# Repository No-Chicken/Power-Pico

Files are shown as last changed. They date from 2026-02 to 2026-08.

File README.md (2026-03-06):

<p align="right">
  <b>中文</b> | <a href="./README_EN.md">English</a>
</p>

<div align="center">
  <h1 align="center">Power-Pico</h1>
  <p align="center">一款产品级的便携式 USB 电流表与低功耗测量分析仪</p>

  
  
  
  
  
  <br>
  
</div>

---

## 📖 项目简介

**Power-Pico** 不仅仅是一个 USB 电流表。它是专为嵌入式开发者设计的**高精度低功耗分析工具**。针对传统电流表在 $\mu A$ 级别测量时的物理局限性，Power-Pico 采用了创新的**多档位自动切换采样**设计，实现了从 $1\mu A$ 到 $5A$ 的全量程覆盖。

<p align="center">
	<a href="https://space.bilibili.com/34154740">bilibili主页 </a> |
	<a href="">演示视频 </a> |
    <a href="https://oshwhub.com/no_chicken/powerpico">硬件开源 </a>
</p>

<p align="center">
	
</p>

### ✨ 核心特性

- **uA 级高精度**：采用 INA190 零漂移放大器，配合三档电阻分段采样。
- **协议诱骗**：支持 PD2.0 PPS 协议诱骗，最高支持 20V/5A 诱骗输出。
- **高性能 UI**：基于 STM32F411 + LVGL v9.2，提供丝滑的实时波形显示。
- **优雅上位机**：配套 PySide6 开发的 Power-Pico Client，支持数据导出与实时功耗分析。
- **通用Type-C**：全部接口都是Typec-C，可以方便的外接Type-C转鳄鱼头等接头。
- **3D打印外壳**：提供完整的方便用户组装的 3D 打印外壳与亚克力面板设计方案。

---

## 🛠️ 硬件参数

<div align="center">

| 模块 | 选型 | 优势 |
| :--- | :--- | :--- |
| **主控** | STM32F411CEU6 | 100MHz 高主频，支持 DSP 指令加速波形处理 |
| **电流采样** | INA190 | 0.5nA 输入偏置电流，μA 级测量的核心保证 |
| **ADC** | 12-bit (STM32 Internal) | 配合 DMA 实现 10kHz 以上的高速稳定采样 |
| **屏幕** | 1.54" TFT (ST7789) | 240x240 分辨率，高对比度显示 |

</div>

---

## 🚀 快速复刻

### 1.硬件
自行焊接硬件，或购买淘宝已经焊接组装好的套件
立创硬件开源界面：https://oshwhub.com/no_chicken/powerpico

### 2. 固件自行编译烧录
项目基于 Keil MDK 开发：
1. 克隆仓库：`git clone https://github.com/kingham/Power-Pico.git`
2. SWD口烧录BootLoader
3. 自行编译PowerPico，编译好生成的`.bin`文件再使用PowerPico Client烧录即可

### 3. 结构组装

实物组装如下图所示:

<p align="center">
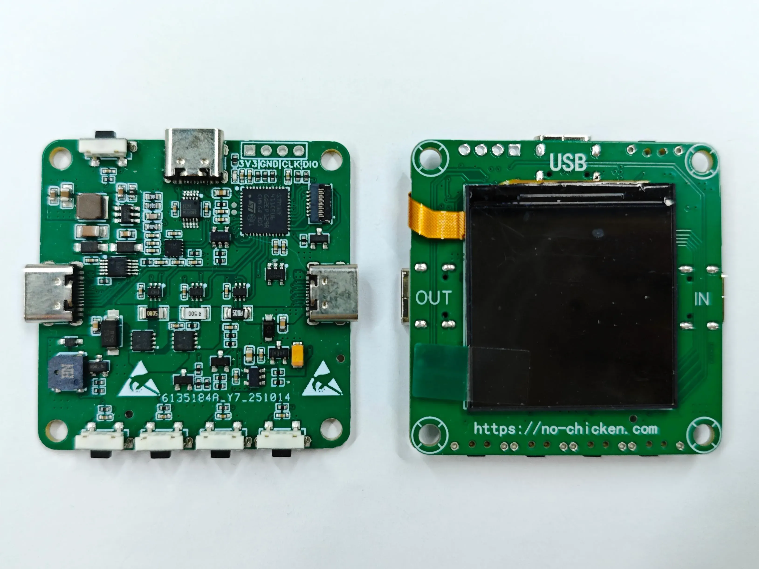
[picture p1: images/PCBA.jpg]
	
    &nbsp;
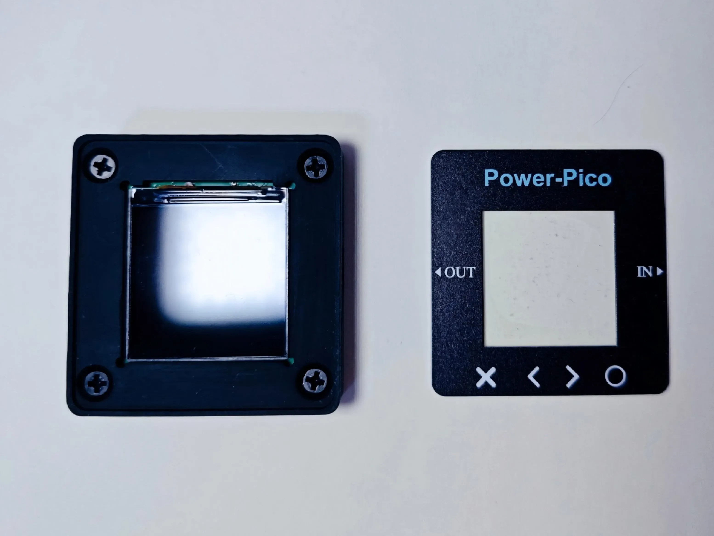
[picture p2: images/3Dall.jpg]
    
</p>

3D爆炸图如下图所示:

<p align="center">
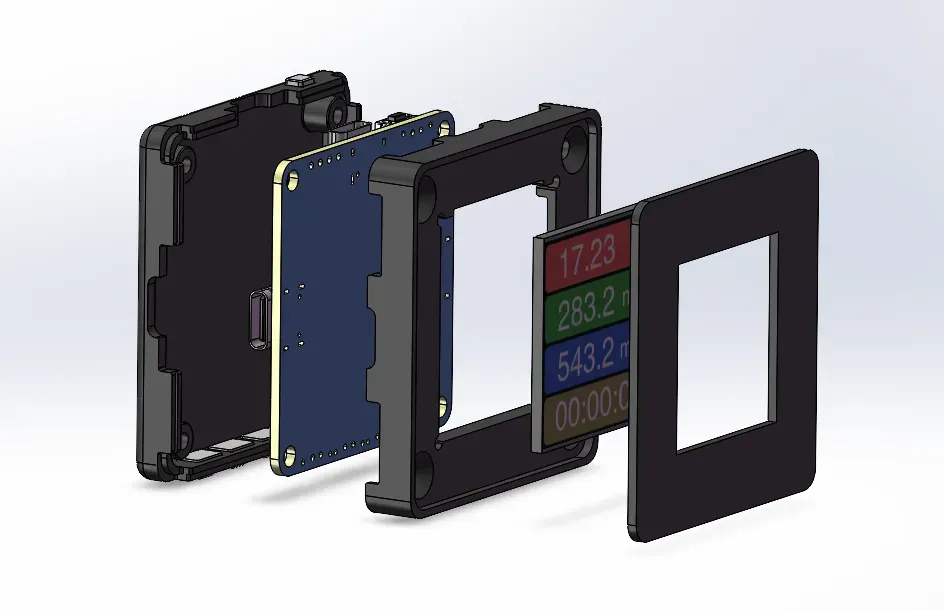
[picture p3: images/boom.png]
	
    &nbsp;
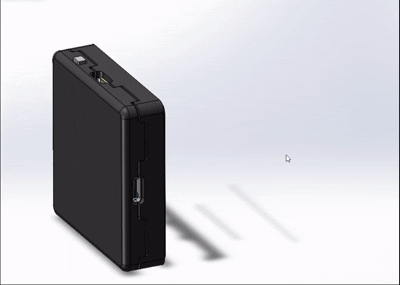
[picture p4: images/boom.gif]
    
</p>

### 4. 上位机运行
安装PowerPico Client使用即可，目前只支持windows操作系统。

## 🛠️ 使用说明

1. 硬件操作说明

    Power-Pico的按键操作说明，和各个界面展示，如下图所示。顶部按键为 **换页/Boot** 按键，长按住顶部按键再上电，会直接进入Boot模式强制升级模式。

    Power-Pico硬件目前只支持 **中文简体/English** 2种语言。

    <p align="center">
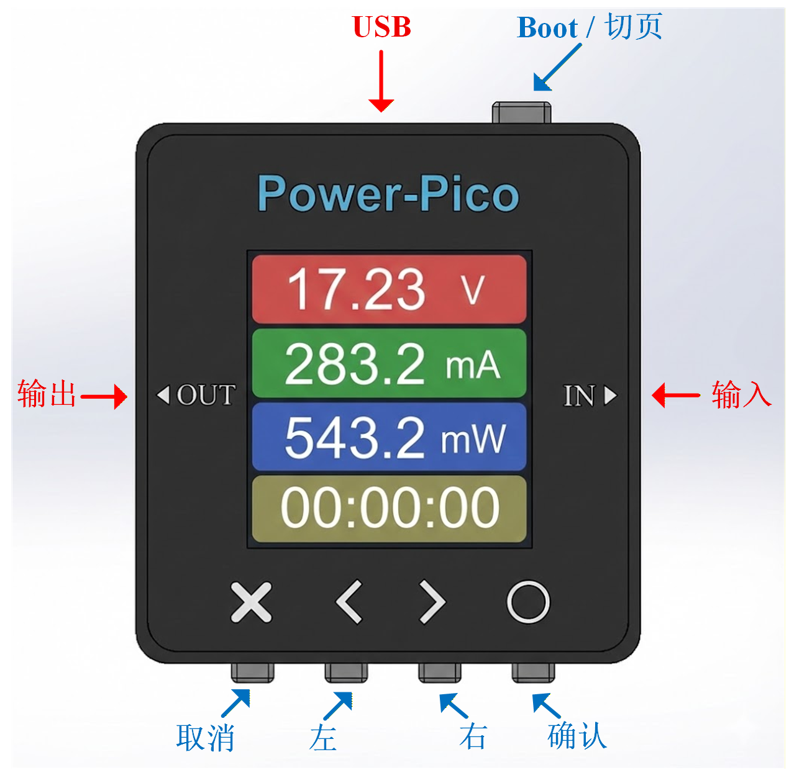
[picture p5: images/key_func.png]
        
        &nbsp;
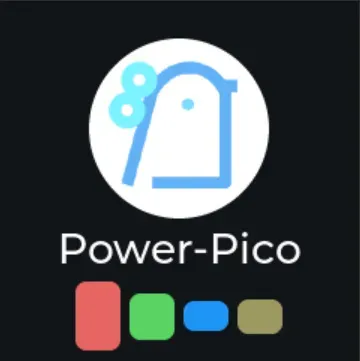
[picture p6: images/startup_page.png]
        
    </p>
    <p align="center">
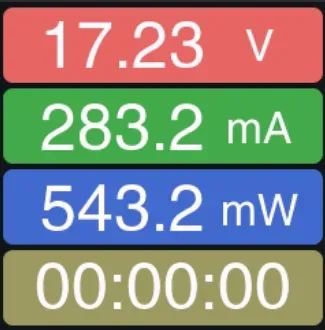
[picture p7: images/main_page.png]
        
        &nbsp;
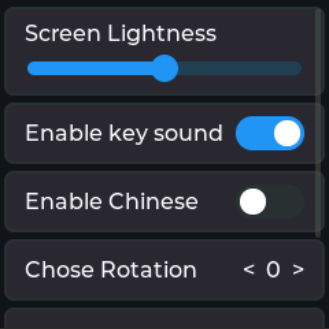
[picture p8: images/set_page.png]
        
    </p>
    <p align="center">
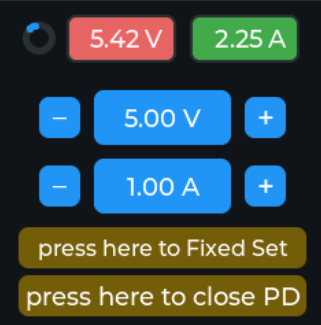
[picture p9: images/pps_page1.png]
        
        &nbsp;
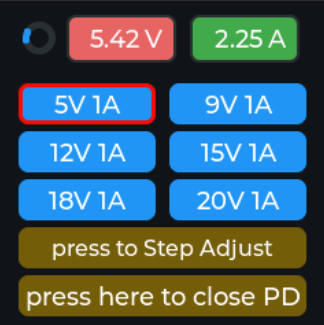
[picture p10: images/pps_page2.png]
        
    </p>

2. PPS诱骗操作说明

    首先进入setting界面，来到诱骗选项，点击确认，进入诱骗，然后即可进行电压调节。注意：目前只支持 PPS 诱骗！测试时需要看下充电头协议支持！

    <p align="center">
        
    </p>

3. 客户端操作说明

    PowerPico Client电脑客户端可以用于波形查看、记录、导出；能够进行对下位机硬件的固件升级。客户端目前支持 **中文简体/中文繁体/English/日本語** 4种语言。

    PowerPico Client客户端上位机的具体使用方法详见：[客户端操作说明](https://no-chicken.com/content/Power-Pico/UserManual/client_operation.html)

    <p align="center">
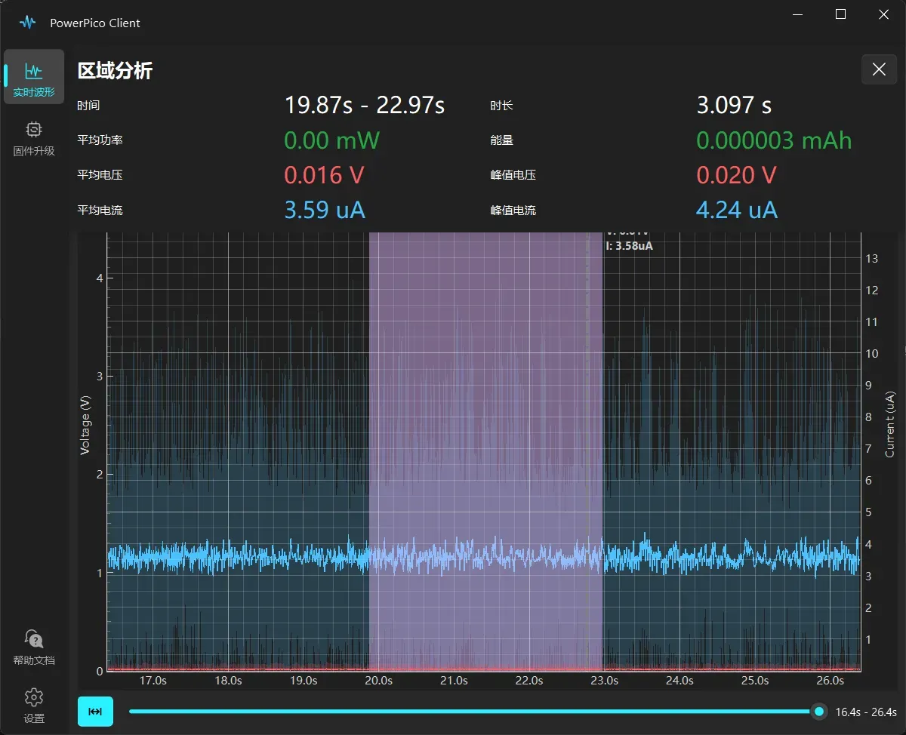
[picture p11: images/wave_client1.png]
        
        &nbsp;
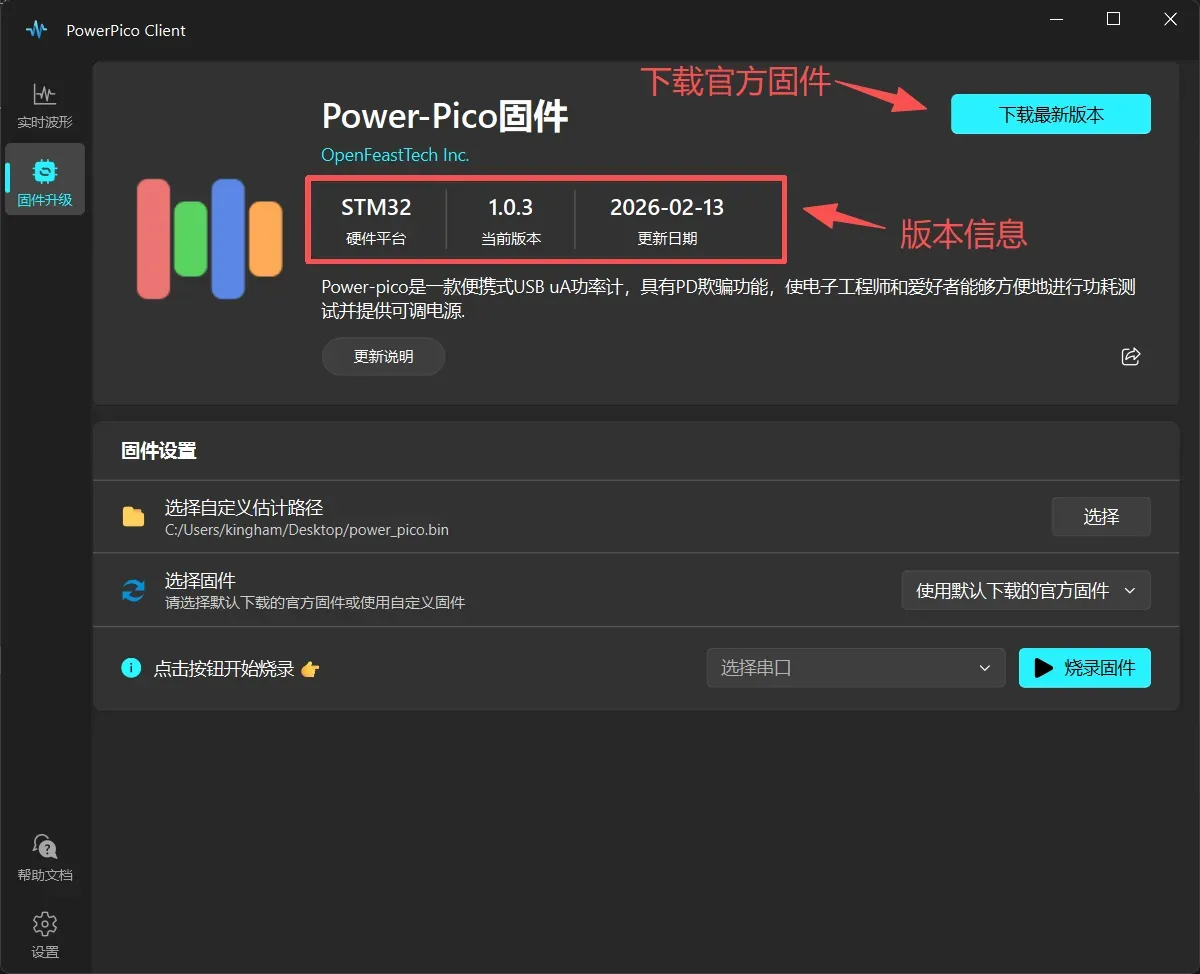
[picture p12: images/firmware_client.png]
        
    </p>
    <p align="center">
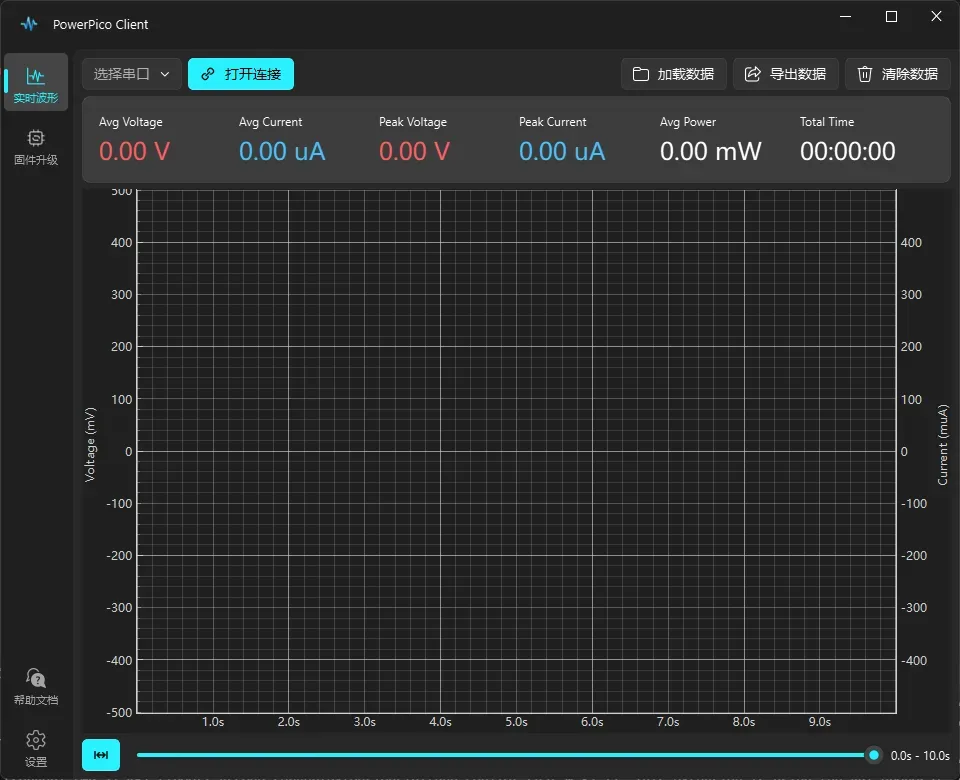
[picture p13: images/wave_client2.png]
        
        &nbsp;
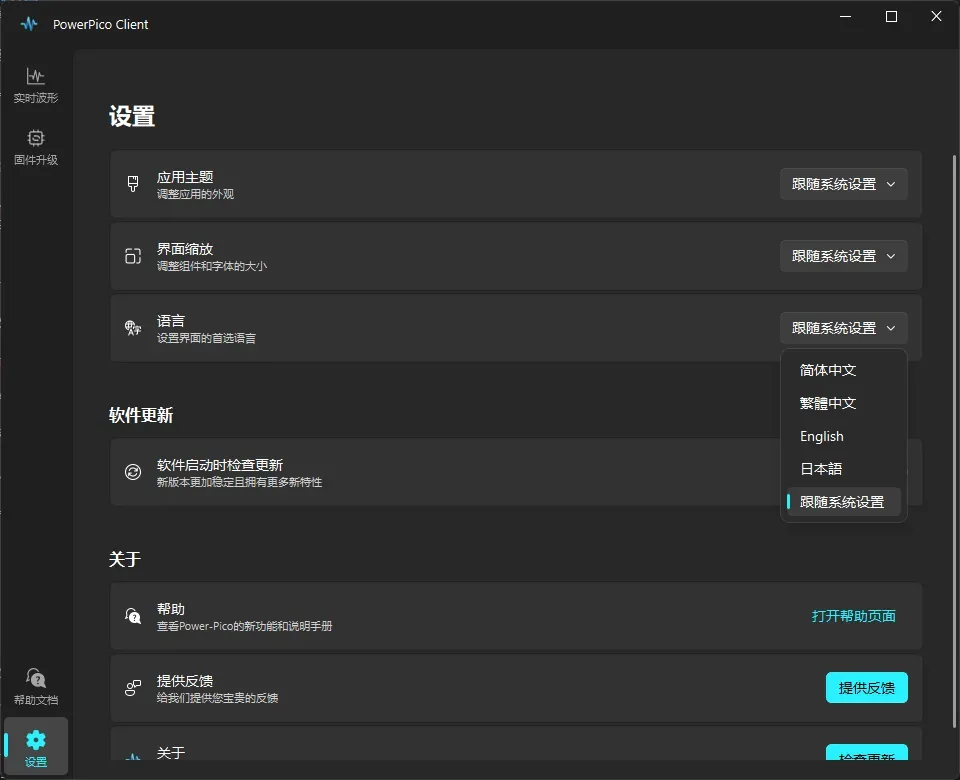
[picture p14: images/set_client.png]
        
    </p>

## 🔍️ 精度测量

<b>注意: Type-C接口线的电源和GND之间是有电阻的，一般是MΩ级别，会影响测量</b>

使用 SDM3055 六位半万用表进行对比，如下图所示：

<p align="center">
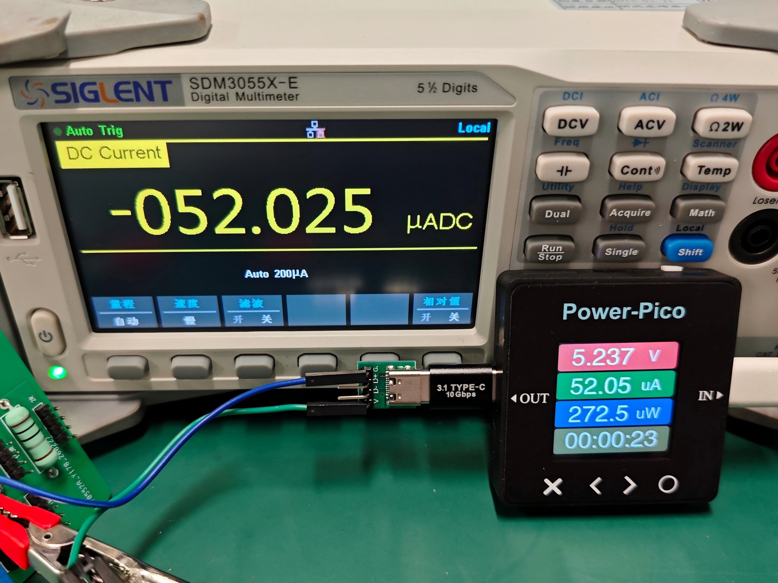
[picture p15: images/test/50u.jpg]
    
    &nbsp;
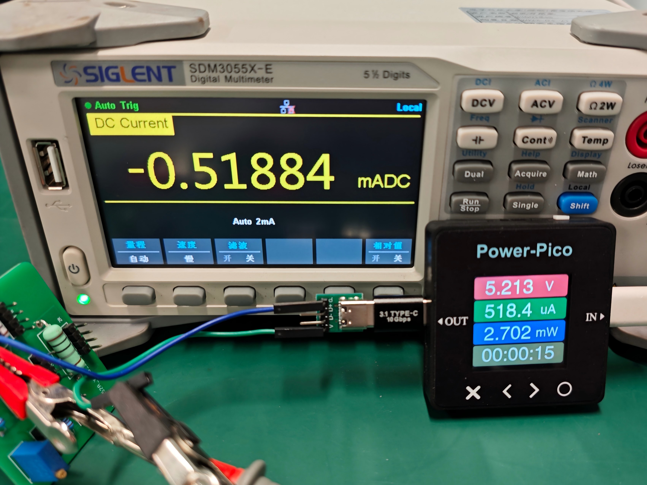
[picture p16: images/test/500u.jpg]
    
</p>
<p align="center">
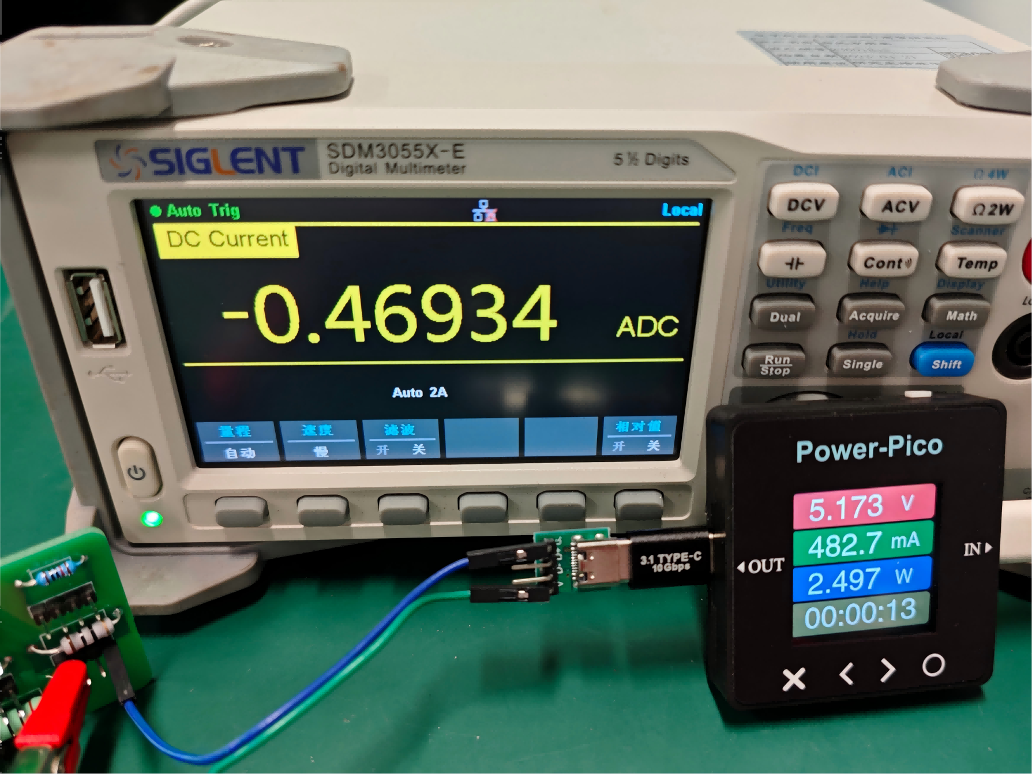
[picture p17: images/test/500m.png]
    
    &nbsp;
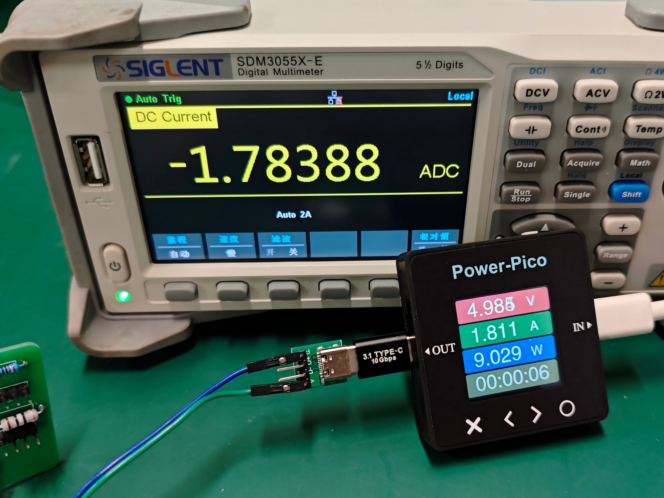
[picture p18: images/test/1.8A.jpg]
    
</p>

<div align="center">

| SDM3055示数 | Power-Pico示数 | 绝对误差 | 相对误差 |
| :--- | :--- | :--- | :--- |
| 52.03 uA | 52.05 uA | 0.02uA | 0.4% |
| 518.84 uA | 518.4 uA | 0.5 uA | 1.0% |
| 5.22 mA |	5.29 mA | 0.07 mA |	1.3% |
| 469.3 mA | 482.7 mA |	13.4 mA | 2.9% |
| 1.78 A | 1.81 A |	0.03 A | 1.7% |
| 5.19 V | 5.24 V | 0.05 V | 1.0% |
| 15.20 V | 15.56 V | 0.36 V | 2.4% |
| 19.98 V | 20.17 V | 0.19 V | 1.0% |

</div>

---

## 📂 项目结构
```text
Power-Pico/
├── Firmware/        # 固件，包括BootLoader.hex和App.bin
├── Hardware/        # 原理图
├── 3D models/       # STL文件，用于3D打印外壳
└── Software/        # PowerPico的MDK软件工程，包括BootLoader和App
```

---

## 💻代码框架

跟以前的项目一样，采用了 BootLoader + App 的结构，方便USB升级。程序分区如下图所示。

<ul>
<li>起始的sector0,1,2的48kB区域为BootLoader区域</li>
<li>第3个sector的16kB区域为升级信息区域，用于开机校检App完整性，具体的校检内容详见BootLoader代码</li>
<li>从0x08010000第4个扇区开始后的区域，都为App区域（之所以不做AB分区是片上Flash不够）</li>
</ul>

<p align="center">
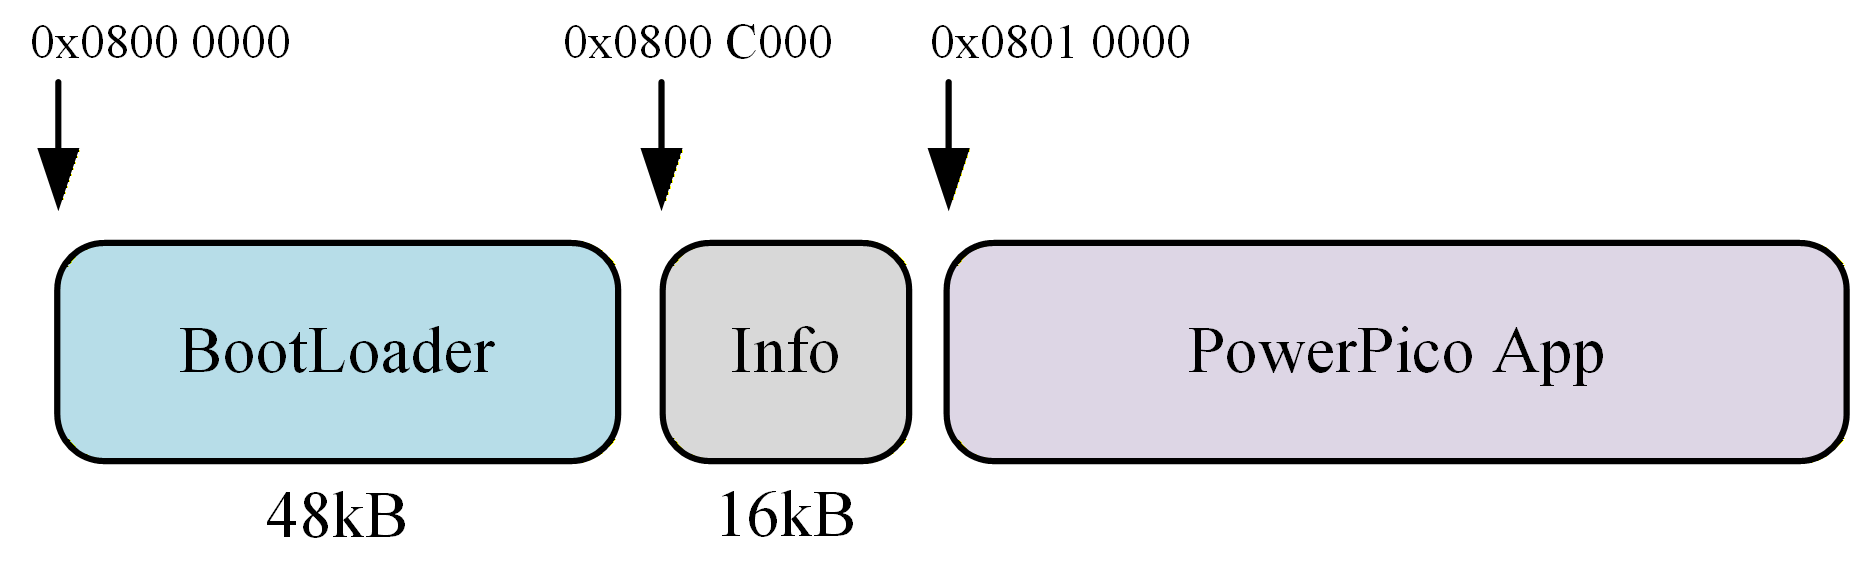
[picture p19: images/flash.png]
    
</p>

使用USB进行高速数据传输，数据包组成如下图所示。每个数据包100组数据，加上头共计711Bytes。

<p align="center">
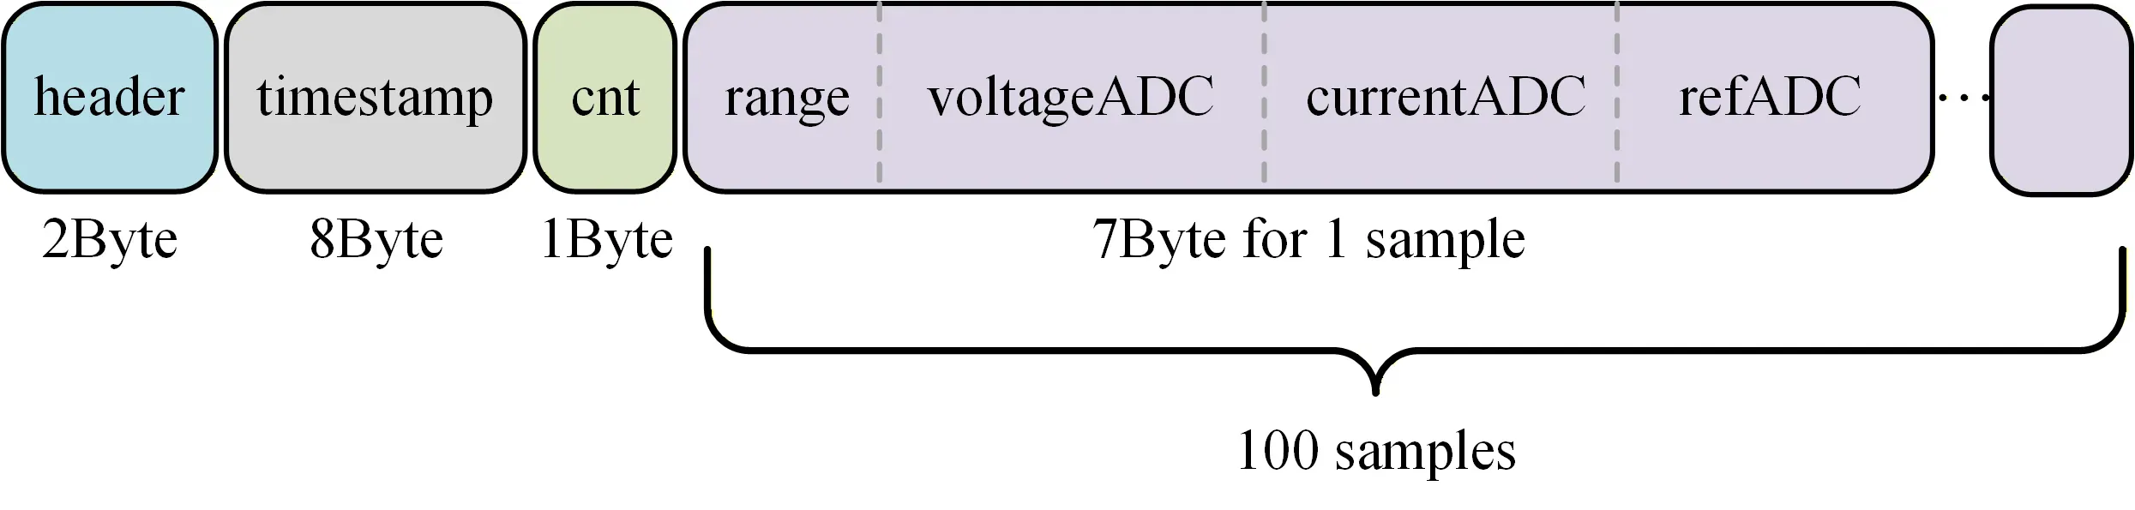
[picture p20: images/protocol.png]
    
</p>

---

## 📖 参考资料

<ul>
    <li style="margin-bottom:8px"><a href="https://github.com/ryan-ma/PD_Micro">[1] PD_Micro - ATMega32U4 Arduino板上的USB-C PD3.0 PPS</a></li>
    <li style="margin-bottom:8px"><a href="https://wiki.luatos.com/iotpower/cc/index.html">[2] 合宙 Power CC 外壳结构</a></li>
    <li style="margin-bottom:8px"><a href="https://doc.qt.io/qtforpython-6/PySide6/QtWidgets/index.html">[3] PySide6手册</a></li>
    <li style="margin-bottom:8px"><a href="https://qfluentwidgets.com/zh/pages/about">[4] QFluentWidgets - 让QT再次伟大</a></li>
    <li style="margin-bottom:8px"><a href="https://pyqtgraph.readthedocs.io/en/latest/getting_started/index.html">[5] PyQtGraph 使用手册</a></li>
    <li style="margin-bottom:8px"><a href="https://www.st.com/en/development-tools/stsw-stm32102.html">[6] STM32 USB 虚拟串口driver案例</a></li>
    <li style="margin-bottom:8px"><a href="https://github.com/lvgl/lvgl">[7] LVGL - Embedded graphics library </a></li>
</ul>

---

## 🤝 提交共享

欢迎提交 Issue 或 Pull Request 来增加项目功能，或修改代码bug!!

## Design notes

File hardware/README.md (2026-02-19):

the hardware project is opened on JLC: https://oshwhub.com/no_chicken/powerpico

硬件开源工程详见嘉立创开源平台：https://oshwhub.com/no_chicken/powerpico

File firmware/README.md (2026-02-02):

这个文件夹存放的是PowerPico-V2 USB版本的BootLoader和APP固件。

请烧录BootLoader.hex之后，再用客户端通过ymodem协议烧录APP.bin。

注意，烧录完BootLoader再装外壳，不然SWD烧录口再内部，拆外壳很麻烦的。

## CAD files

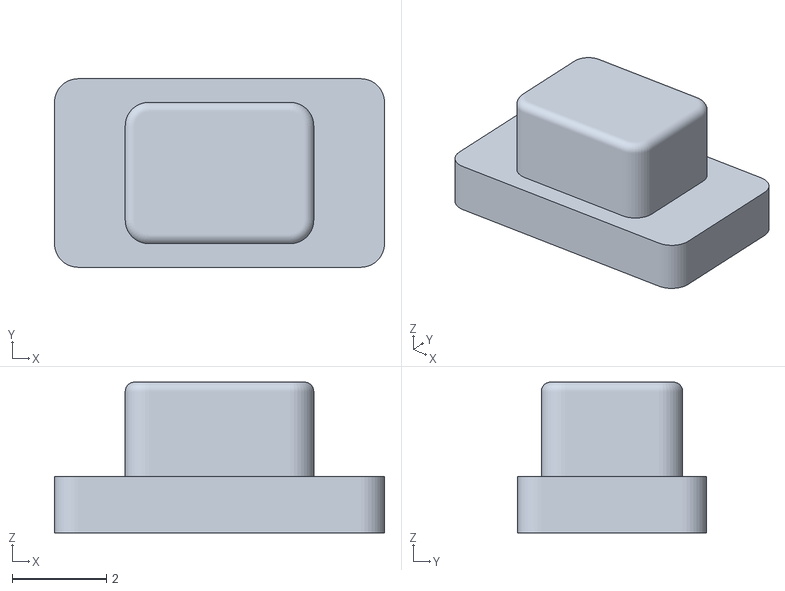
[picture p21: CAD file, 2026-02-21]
3D models/按钮.STL
7.00 x 4.00 x 3.20

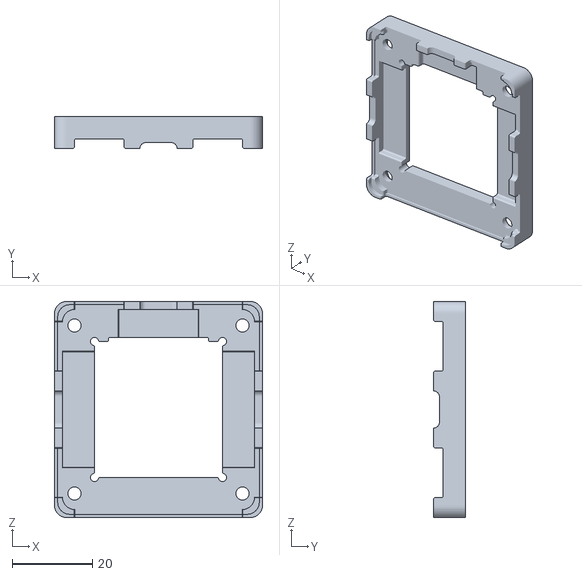
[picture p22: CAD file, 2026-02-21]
3D models/上盖.STL
52.0 x 8.00 x 54.0

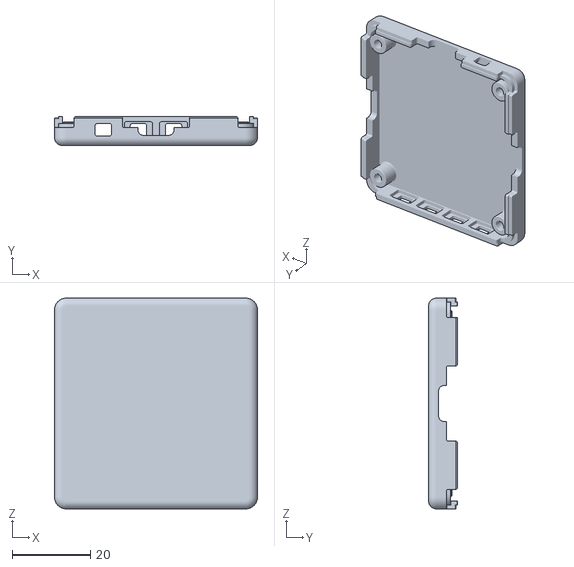
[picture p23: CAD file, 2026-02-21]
3D models/底板.STL
52.0 x 7.40 x 54.0

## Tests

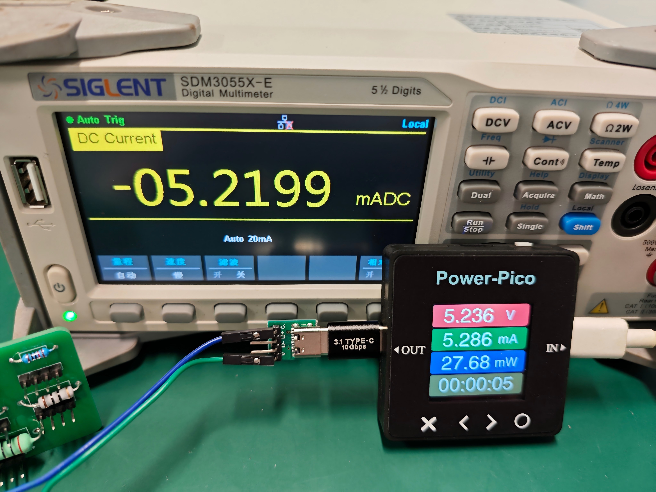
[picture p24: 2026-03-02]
images/test/5m.jpg

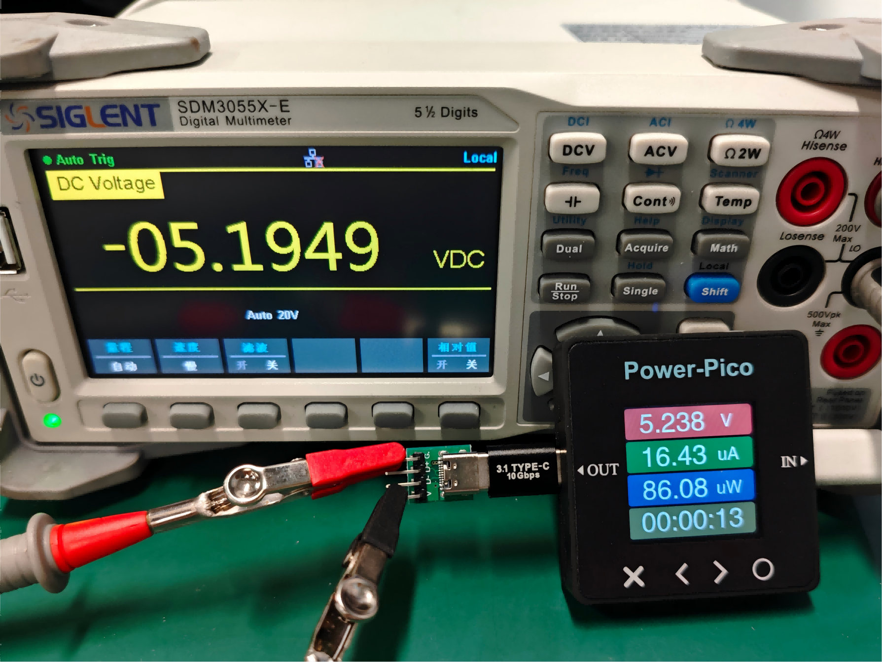
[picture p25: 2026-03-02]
images/test/5V.png

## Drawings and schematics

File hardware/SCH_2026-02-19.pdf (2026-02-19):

### GND

### GND

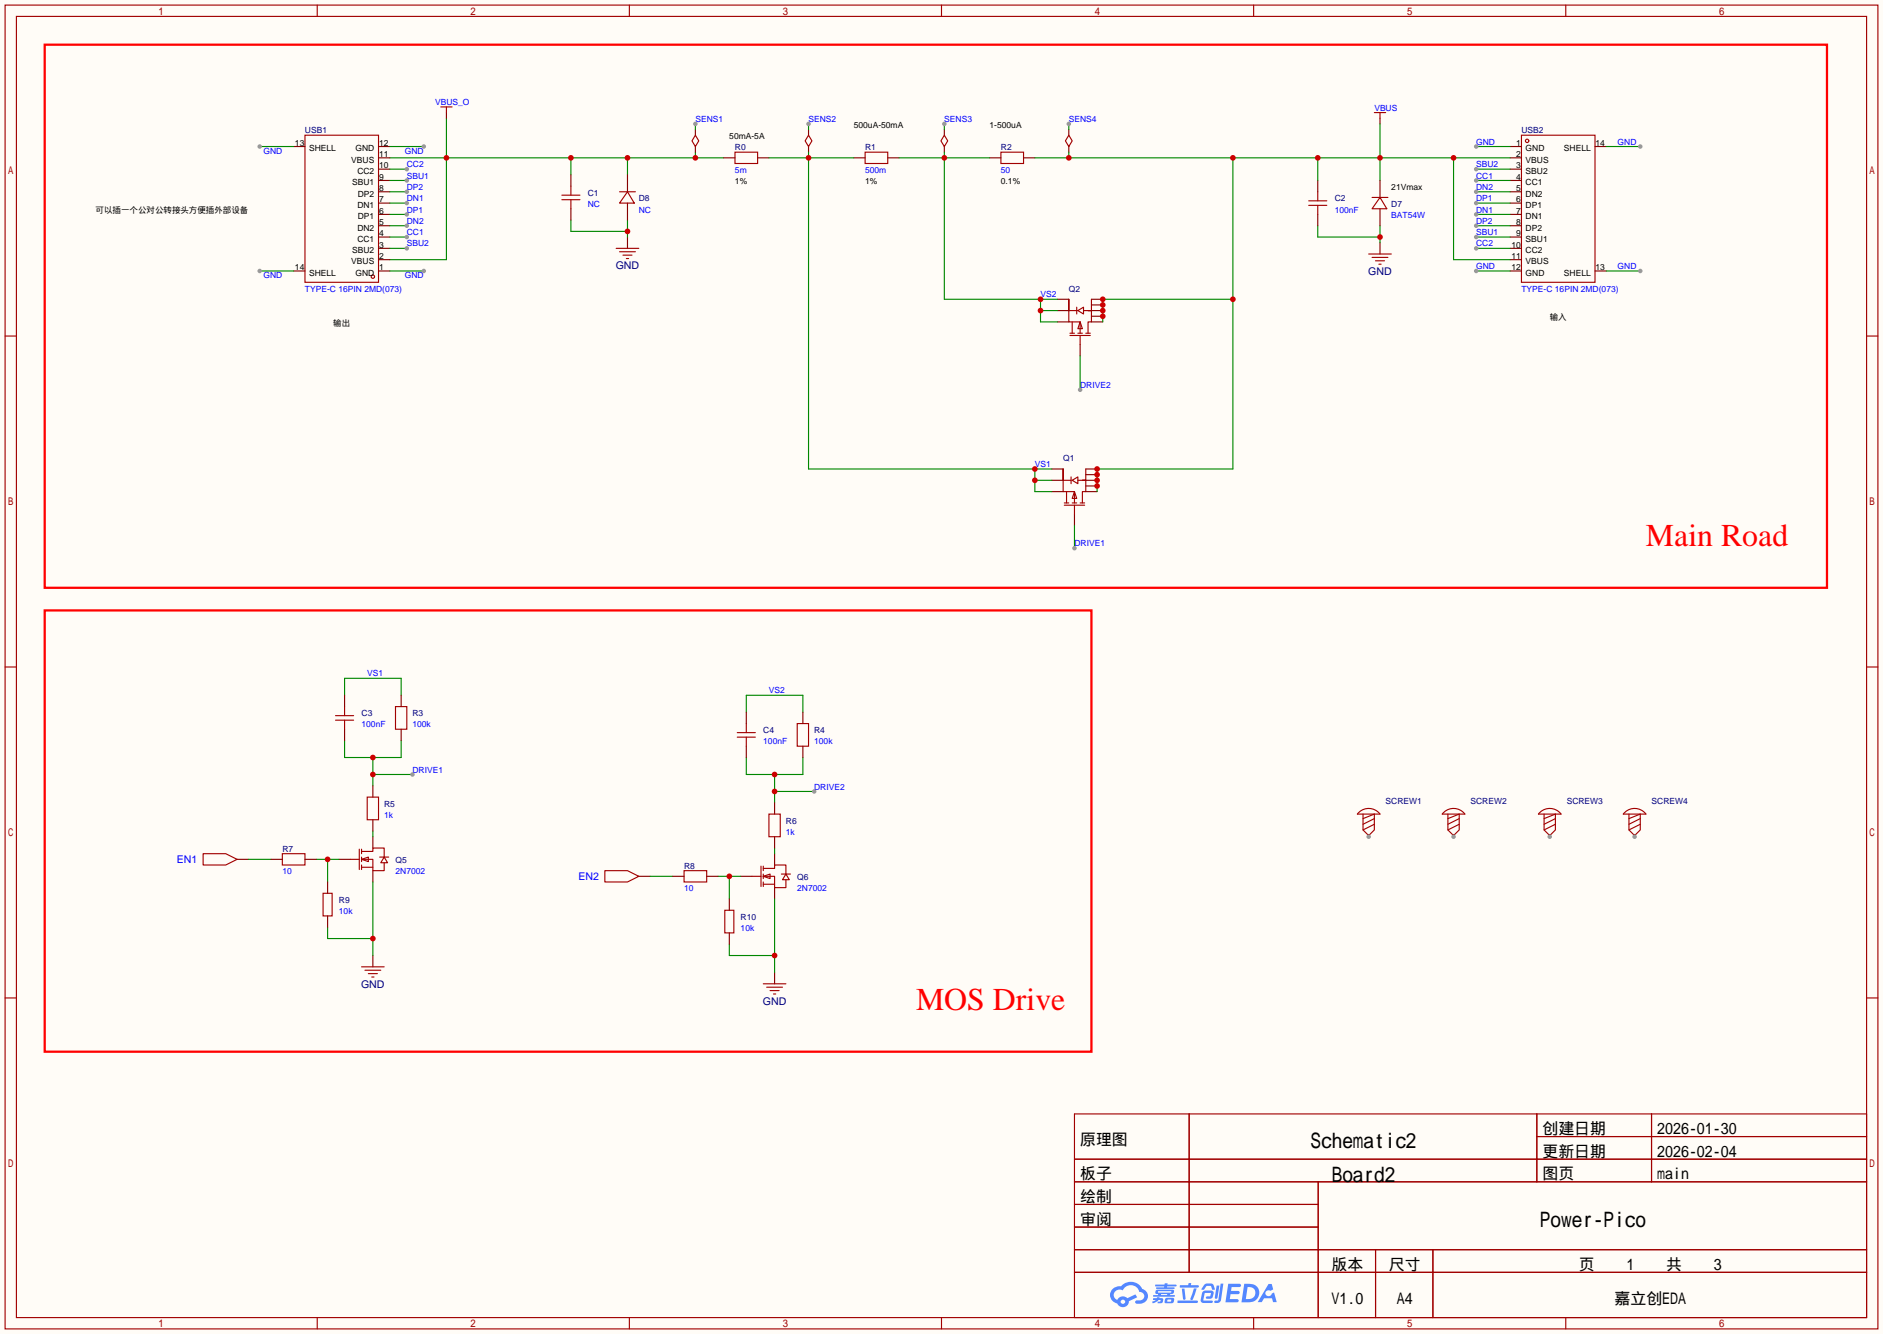
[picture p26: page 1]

原理图 | Schematic2 | 创建日期 | 2026-01-30

更新日期 | 2026-02-04

板子 | Board2 | 图页 | main
绘制 | | Power-Pico
审阅

V1.0 | A4 | 嘉立创EDA

### VADC

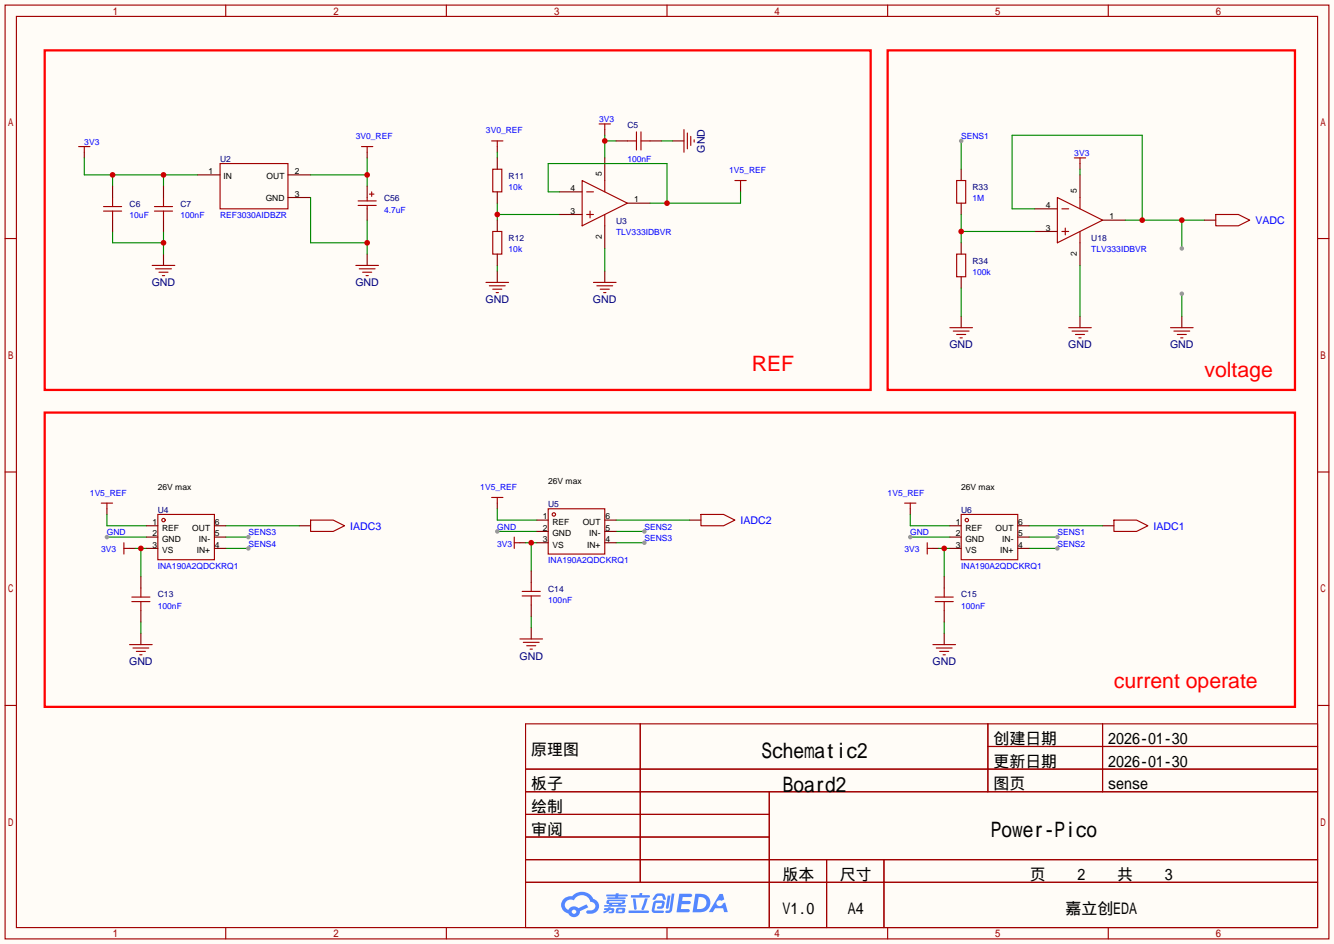
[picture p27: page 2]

原理图 | Schematic2 | 创建日期 | 2026-01-30

更新日期 | 2026-01-30

板子 | Board2 | 图页 | sense
绘制 | | Power-Pico
审阅

EN1

EN2

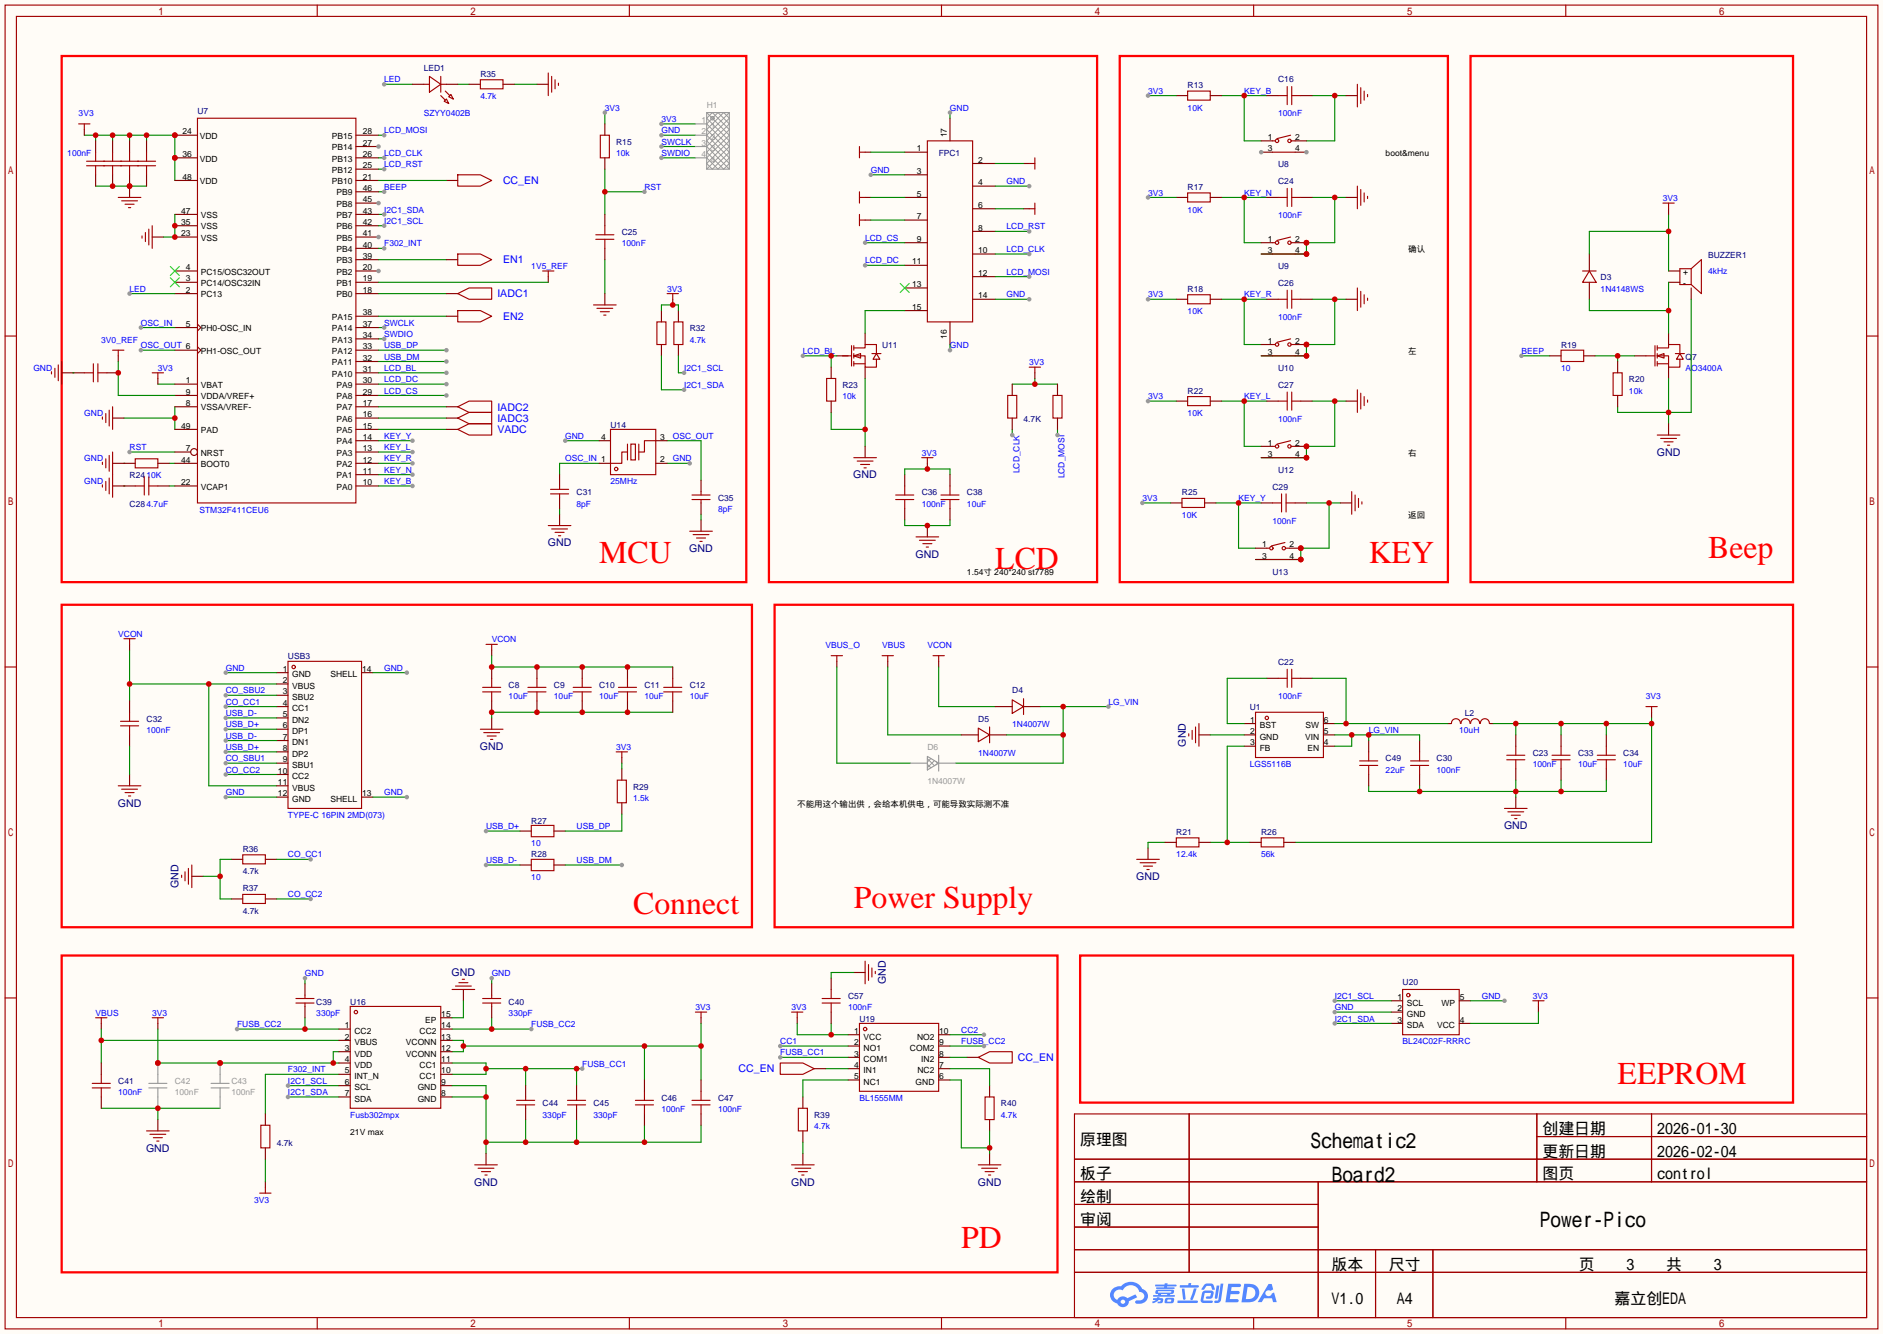
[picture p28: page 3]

原理图 | Schematic2 | 创建日期 | 2026-01-30

更新日期 | 2026-02-04

板子 | Board2 | 图页 | control
绘制 | | Power-Pico
审阅

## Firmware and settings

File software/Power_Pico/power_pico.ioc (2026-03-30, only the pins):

Mcu.UserName=STM32F411CEUx
PA10.Signal=S_TIM1_CH3
PA11.Signal=USB_OTG_FS_DM
PA12.Signal=USB_OTG_FS_DP
PA13.Signal=SYS_JTMS-SWDIO
PA14.Signal=SYS_JTCK-SWCLK
PA5.Signal=ADCx_IN5
PA6.Signal=ADCx_IN6
PA7.Signal=ADCx_IN7
PB0.Signal=ADCx_IN8
PB1.Signal=ADCx_IN9
PB10.Signal=GPIO_Output
PB13.Signal=SPI2_SCK
PB15.Signal=SPI2_MOSI
PB4.Signal=GPIO_Input
PB6.Signal=I2C1_SCL
PB7.Signal=I2C1_SDA
PB9.Signal=S_TIM4_CH4
PC13-ANTI_TAMP.Signal=GPIO_Output

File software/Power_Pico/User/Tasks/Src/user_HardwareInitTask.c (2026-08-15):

/* Private includes -----------------------------------------------------------*/

// includes
// sys
#include "tim.h"
#include "adc.h"
#include "user_AdcDataStrategy.h"
#include "i2c.h"

// user
#include "user_TasksInit.h"

// bsp
#include "key.h"
#include "lcd.h"
#include "lcd_init.h"
#include "gate.h"
#include "fusb302_dev.h"
#include "BL24C02.h" // settings

// ui
#include "lvgl.h"
#include "lv_port_disp.h"
#include "ui.h"

/* Private typedef -----------------------------------------------------------*/

/* Private define ------------------------------------------------------------*/

/* Private variables ---------------------------------------------------------*/

/* Private function prototypes -----------------------------------------------*/


/**
  * @brief  hardwares init task
  * @param  argument: Not used
  * @retval None
  */
void HardwareInitTask(void *argument)
{
	while(1)
	{
    vTaskSuspendAll();

    // gate, for current flow route selection, high current by default
    Gate_Port_Init();
    flow_route_selection(HIGH_CUR);

    // system settings and calibration must be ready before sampling starts
    if(!EEPROM_Init_Check()) {
      EEPROM_SysSetting_Get();
    }
    Gate_Set_Mode(Sys_Get_CurrentRangeMode());

    // usb init
    MX_USB_DEVICE_Init();

    // ADC sample start
    HAL_ADC_Start_DMA(&hadc1, (uint32_t *)adc_raw_buffer, ADC_TIMES*2 * ADC_CHANNELS); /*启动ADC的DMA传输，配合定时器触发ADC转换  12位的ADC对应0-4095 */
    HAL_TIM_Base_Start(&htim2); /*开启定时器，用溢出时间来触发ADC*/

    // PWM Start for LCD backlight
    HAL_TIM_PWM_Start(&htim1,TIM_CHANNEL_3);

    // beep
    // HAL_TIM_PWM_Start(&htim4,TIM_CHANNEL_4);

    // key
    Key_Init();

    // FUSB CC pin dis connect
    HAL_GPIO_WritePin(GPIOB, GPIO_PIN_10, GPIO_PIN_RESET);

    // FUSB302 init
    fusb302_dev_init();

    // lcd
    // done in lvgl disp init

    // tim5 for elapsed time (us)
    HAL_TIM_Base_Start(&htim5);

    // ui
    // LVGL and disp init
    lv_init();
    lv_port_disp_init();
    ui_init();

    xTaskResumeAll();
		vTaskDelete(NULL);
	}
}

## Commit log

2025-08-10 add dma
2025-08-14 update the way that date send to uart. Add Flow route selection Algorithm
2025-08-18 add uart trans dma
2025-08-18 test using dma send adc datas in buffer, via uart
2025-08-18 add uart_tx dma
2025-08-23 更改波特率
2025-09-15 增加获取电压电流数据的方法
2025-09-22 增加queue操作
2025-09-22 更新LCD地址偏移
2025-09-22 更新硬件初始化中队列操作
2025-09-22 更新UI
2025-10-07 增加注释
2025-10-07 更改page切换逻辑
2025-10-07 外置timecount，deinit时置0
2025-10-09 添加set page
2025-10-09 增加LCD动态翻转的函数
2025-10-09 更新cubemx
2025-10-11 降低BootLoader中串口波特率
2025-10-11 加入按键切换聚焦选项
2025-10-19 更新界面
2025-10-19 加入串口消息处理任务
2025-10-19 加入串口接收
2025-10-19 加入EEPROM存储设置
2025-10-19 加入EEPROM存储系统设置
2025-10-20 加入I2C
2025-11-17 加入chart page
2025-11-25 关闭chart page
2025-11-26 开机界面加入动画
2025-11-26 更新开机界面动画
2025-11-27 更新开机动画
2025-12-02 更新按键程序，加入时钟源，加入连击功能
2025-12-02 更新按键
2025-12-02 更新注释
2025-12-02 更新默认repeat时间
2025-12-03 更新API
2025-12-03 删除部分内容
2025-12-03 更新工程设置
2025-12-05 加入UI层与PD诱骗处理任务的信号通信
2025-12-05 定义PD相关信号
2025-12-05 加入PD快充诱骗
2025-12-06 外置一个全局UI定时器，定时全刷新LCD
2025-12-06 更改刷新时间
2025-12-06 更新固件文件
2026-01-15 更新菜单处理逻辑
2026-01-28 加入国际化（翻译）
2026-01-28 更新固件
2026-01-28 加入字体
2026-01-28 更新翻译
2026-01-28 更新工程
2026-02-01 更新跳转逻辑
2026-02-02 删除RTC，改用TIM进行非中断定时时间戳
2026-02-04 更新LCD刷新模式
2026-02-05 gate功能只放mos管的开关关闭的API，删除其他
2026-02-05 加入中断
2026-02-05 删除data queue
2026-02-07 降低SPI+DMA优先级
2026-02-07 更换串口为USB
2026-02-08 更新地址
2026-02-08 更新版本
2026-02-08 删除多余include
2026-02-09 更新客户端
2026-02-13 加入状态
2026-02-13 上传固件
2026-02-19 更新1.0.3
2026-02-19 删除.vscode
2026-02-19 更新readme
2026-02-21 加入3D模型
    [上盖.STL, 底板.STL, 按钮.STL]
2026-02-21 加入弹窗
2026-02-21 更新项目说明
2026-02-26 打包keil_MDK的工程
2026-02-26 加入忽略项
2026-02-26 修改浮点fpu
2026-02-28 更新链接文件
2026-03-15 加入设置旋转函数的冲突避免
2026-03-15 加入USB是否已配置的函数
2026-03-15 改SPI DMA数据宽度；LCD中加入color翻转
2026-03-25 修改SPI transmit等待时间
2026-03-25 取消全局变量通知更新固件，改为osThreadFlagsWait
2026-03-25 修改LVGL线程的优先级
2026-03-30 加入GPIO下拉
2026-04-05 修改笔误
2026-04-05 加入信息
2026-04-05 删除老打包
2026-04-25 更新LVGL版本为9.5
2026-05-02 更新LCD刷新为异步
2026-05-02 更新固件版本
2026-05-04 分离ADC数据处理逻辑
2026-05-04 更新ADC数据处理
2026-05-08 增大栈空间修复卡顿bug
2026-05-08 修改LCD驱动
2026-06-26 修正注释
2026-06-26 加入pd fixed
2026-06-26 修改命名
2026-06-26 加入pd fixed界面
2026-08-15 更新命令CMD
2026-08-16 更新1.1.7版本
2026-10-24 build(cmake): integrate PR6 GCC and Bootloader-tested memory layout
    Adapt the build and memory-layout fixes from EudaiG's PR #6 commit
    d5f2f644e38a072c6729e283662276474949d291: GCC port, source collection,
    NuttX exclusion, float printf, linker stack bounds and LVGL buffers.
    Keep unrelated presets/options, Keil settings and later PR changes out.
    Add missing declarations and correct include case for strict GCC builds.
    Document attribution, binary comparison and remaining hardware regression.
    GCC 14.2.1 Release/MinSizeRel pass with implicit declarations as errors.
    User confirmed original c1 Bootloader startup; integrated image still
    requires hardware regression because declaration fixes change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

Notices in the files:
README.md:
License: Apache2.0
